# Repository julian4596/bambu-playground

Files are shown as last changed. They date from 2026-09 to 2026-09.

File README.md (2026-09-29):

# Ultralight Spacerless Gridfinity

Open `Ultralight_Spacerless_Gridfinity.scad` in OpenSCAD. Style 0 generates
open-bottom, rounded rings with chamfered seating faces and diamond-shaped
gaps where four cells meet. Drawer fitting and print-bed tiling remain available.

## Reference dimensions and reconstruction

The supplied reference screenshots measure a 2×2 plate at **84×84×4.25 mm**.
Their close-ups show sloped inner faces and a small lower transition, rather
than the previous flat opening and outward underside recess.

Paul Bone's [parameters.py](https://github.com/PaulBone/gfthings/blob/main/src/gfthings/parameters.py)
defines a 42 mm pitch and profile stages of 0.8, 1.8, and 2.15 mm.
[GFProfile.py](https://github.com/PaulBone/gfthings/blob/main/src/gfthings/GFProfile.py)
uses those stages for the chamfered profile. This is useful dimensional
reference, but its baseplate is not established as the model in the screenshots.
The local `gridfinity-rebuilt-openscad/src/core/gridfinity-baseplate.scad`
uses a related profile with a 0.7 mm lower chamfer and a 5 mm overall plate.
Neither source proves the exact 4.25 mm reference cross-section.

Style 0 therefore uses an explicit assumption: trim 0.5 mm from the bottom of
the 4.75 mm profile, retaining 0.3 mm of lower chamfer, 1.8 mm of straight wall,
and 2.15 mm of upper chamfer. The top opening remains 41.5 mm with 4 mm corner
radius; each cell's outer outline remains 42 mm with 4.25 mm corner radius.
The corresponding straight opening at the bottom is 36.6 mm, and at the middle
it is 37.2 mm. Straight outer rails are 0.25 mm at the top, 2.4 mm in the middle,
and 2.7 mm at the bottom; interior dividers have twice those widths.
These are derived candidate dimensions, not measurements of the reference.

Later underside close-ups show a recessed channel under each rail with a
sloping interior and narrow edge rims. Style 0 now subtracts a tapered rounded
annular channel under each cell, including around corners. The candidate defaults
are a 1.8 mm depth, 0.4 mm rims at the mouth, and a 0.3 mm wide channel roof.
The resulting mouth is approximately 1.9 mm wide along straight rails. Adjacent
cells retain a central rib between their channels. These relief dimensions are
visual estimates, not source-derived dimensions; `underside_relief_depth` and
`underside_relief_rim` expose the estimates for adjustment. `underside_relief`
can disable the channel. The earlier 2.7 mm bottom rail width describes the
envelope before this channel is subtracted.

Styles 1 and 2 retain the full 4.75 mm profile. This source is implemented in
OpenSCAD; the downloaded Python files under `reference/gfthings` are reference
material only and retain their original copyright and license notices.

## Comparison sample

`render_2x2.scad` selects a manual 2×2, style-0, untiled sample. Render it to
compare the candidate with the screenshots. Rendered artifacts are placed in
`output/reference-match/`. Dimensional and mesh checks do not establish printed
fit; the shortened underside profile remains a reconstruction assumption.

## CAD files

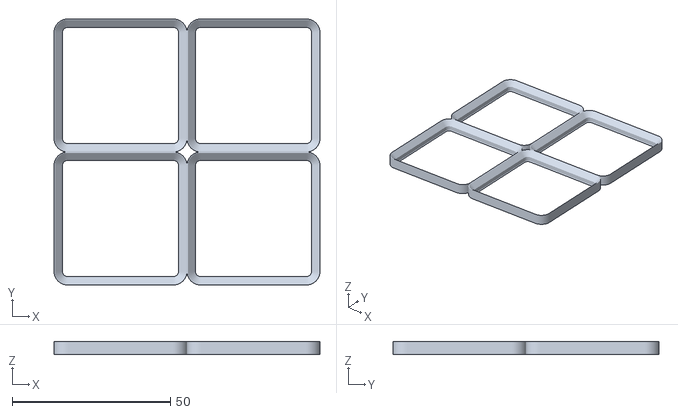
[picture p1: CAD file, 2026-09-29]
output/reference-match/lightest-2x2-relief.stl
84.0 x 84.0 x 4.25

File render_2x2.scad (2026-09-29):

// Parameters follow include so they override the included defaults.
include <Ultralight_Spacerless_Gridfinity.scad>
use_auto_fit = false;
manual_grid_x = 2;
manual_grid_y = 2;
style = 0;
clearance_per_side = 0;
tiling_mode = false;
enable_labels = false;

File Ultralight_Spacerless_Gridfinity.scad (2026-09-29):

// ============================================================================
// Ultralight Spacerless Gridfinity Baseplate
// ============================================================================
// A parametric, MakerWorld-compatible OpenSCAD script that generates
// ultra-lightweight Gridfinity baseplates that auto-fit your drawer
// dimensions with zero wasted space.
//
// Features:
//   - Spacerless auto-fit: input drawer dimensions, get a perfect fit
//   - Three styles: Ultralight (skeleton), Standard (thin floor), Solid
//   - Optional magnet and screw holes
//   - MakerWorld Customizer compatible
//
// Author: Julian (generated with AI assistance)
// License: CC BY-SA 4.0
// ============================================================================

// ---- Gridfinity Standard Constants ----
// These define the Gridfinity standard. Do not change unless you
// understand the Gridfinity specification.
GRID_PITCH     = 42;      // mm - standard grid unit size
TOLERANCE      = 0.25;    // mm - clearance per side (bin-to-baseplate)
WALL_MIN       = 1.2;     // mm - minimum wall thickness (3 × 0.4mm)
MAGNET_D       = 6.0;     // mm - magnet hole diameter
MAGNET_H       = 2.4;     // mm - magnet hole depth
SCREW_D        = 3.2;     // mm - M3 screw hole diameter

// Gridfinity baseplate pocket profile (cross-section, bottom to top):
//   Layer 1: 45° chamfer inward  — 0.8mm tall, narrows 0.8mm per side
//   Layer 2: Vertical wall       — 1.8mm tall, straight
//   Layer 3: 45° chamfer outward — 2.15mm tall, widens 2.15mm per side
CHAMFER_BOT_H = 0.8;
WALL_VERT_H   = 1.8;
CHAMFER_TOP_H = 2.15;
FULL_PROFILE_H = CHAMFER_BOT_H + WALL_VERT_H + CHAMFER_TOP_H; // 4.75mm
LIGHT_PROFILE_H = 4.25; // Overall height measured in the reference screenshots
// Shorten the open-bottom light plate without changing the upper seating profile.
LIGHT_BOTTOM_TRIM = FULL_PROFILE_H - LIGHT_PROFILE_H;

// Pocket dimensions (the void bins sit in)
// At the TOP of the pocket, the opening is the full cell minus tolerance
POCKET_TOP = GRID_PITCH - 2 * TOLERANCE;  // 41.5mm
// The mid-section (after top chamfer, before bottom chamfer)
POCKET_MID = POCKET_TOP - 2 * CHAMFER_TOP_H;  // 37.2mm
// At the BOTTOM, it narrows further
POCKET_BOT = POCKET_MID - 2 * CHAMFER_BOT_H;  // 35.6mm

// ============================================================================
// MakerWorld Customizer Parameters
// ============================================================================

/* [01 — Drawer Dimensions] */
// Inner width of your drawer in mm
drawer_width_mm = 400; // [50:1:1000]
// Inner depth of your drawer in mm
drawer_depth_mm = 500; // [50:1:1000]
// Clearance per side in mm (0.5 recommended)
clearance_per_side = 0.5; // [0:0.1:2]

/* [02 — Grid Override (Optional)] */
// Use auto-fit from drawer dimensions?
use_auto_fit = true;
// Manual grid units in X (only used if auto-fit is OFF)
manual_grid_x = 4; // [1:1:20]
// Manual grid units in Y (only used if auto-fit is OFF)
manual_grid_y = 4; // [1:1:20]

/* [03 — Baseplate Style] */
// 0=Super Light (4.25mm chamfered rings), 1=Standard (thin floor), 2=Solid (thick floor)
style = 0; // [0:Super Light, 1:Standard, 2:Solid]
// Recess a tapered channel into the underside of each light-style cell rail.
underside_relief = true;
// Estimated from reference views, not measured: channel height in mm.
underside_relief_depth = 1.8; // [0.2:0.1:2]
// Material retained at the inner and outer edges of the channel mouth.
underside_relief_rim = 0.4; // [0.3:0.05:0.8]

/* [04 — Extension Distribution] */
// How to distribute leftover space on each axis
// 0=Split evenly both sides, 1=Right/Back only, 2=Left/Front only
extension_mode = 0; // [0:Even Split, 1:Right-Back Only, 2:Left-Front Only]

/* [05 — Options] */
// Add 6mm x 2.4mm magnet holes at grid intersections
magnet_holes = false;
// Add M3 screw holes at grid intersections
screw_holes = false;

/* [06 — Print Bed Tiling] */
// Splitcut the generated plate (manual or auto-fit) into bed-sized tiles.
tiling_mode = true;
// Bed width in mm (tiling only).
bed_x_mm = 256.0; // [100:0.1:500]
// Bed depth in mm (tiling only).
bed_y_mm = 256.0; // [100:0.1:500]
// Reserved margin per bed edge in mm (tiling only).
bed_safe_margin_mm = 2.0; // [0:0.1:20]
// Gap between tiles in mm (scene only).
tile_gap_mm = 10.0; // [0:0.1:50]
// Add tile coordinate labels (tiling only).
enable_labels = true;
// Which part to render? 0=All (Exploded View), 1=Tile 1/1, etc.
part_to_render = 0; // [0:All (Exploded), 1:Tile 1/1, 2:Tile 2/1, 3:Tile 1/2, 4:Tile 2/2, 5:Tile 3/1, 6:Tile 3/2, 7:Tile 3/3, 8:Tile 4/1, 9:Tile 4/2, 10:Tile 4/3]

/* [Hidden] */
$fn = 40;
PROFILE_H = style == 0 ? LIGHT_PROFILE_H : FULL_PROFILE_H;

// ============================================================================
// Auto-Fit Calculation
// ============================================================================

_usable_w = drawer_width_mm - 2 * clearance_per_side;
_usable_d = drawer_depth_mm - 2 * clearance_per_side;

_auto_gx = max(1, floor(_usable_w / GRID_PITCH));
_auto_gy = max(1, floor(_usable_d / GRID_PITCH));

_left_x = _usable_w - _auto_gx * GRID_PITCH;
_left_y = _usable_d - _auto_gy * GRID_PITCH;

gx = use_auto_fit ? _auto_gx : manual_grid_x;
gy = use_auto_fit ? _auto_gy : manual_grid_y;

ext_tx = use_auto_fit ? max(0, _left_x) : 0;
ext_ty = use_auto_fit ? max(0, _left_y) : 0;

// Extension distribution
ext_L = (extension_mode == 0) ? floor(ext_tx / 2) :
        (extension_mode == 2) ? ext_tx : 0;
ext_R = (extension_mode == 0) ? ext_tx - floor(ext_tx / 2) :
        (extension_mode == 1) ? ext_tx : 0;
ext_F = (extension_mode == 0) ? floor(ext_ty / 2) :
        (extension_mode == 2) ? ext_ty : 0;
ext_B = (extension_mode == 0) ? ext_ty - floor(ext_ty / 2) :
        (extension_mode == 1) ? ext_ty : 0;

total_w = gx * GRID_PITCH + ext_L + ext_R;
total_d = gy * GRID_PITCH + ext_F + ext_B;

// Tiling calculations
// We reserve margin for the physical bed edge + ~15mm for puzzle joints & frame extensions
cells_per_tile_x = tiling_mode ? max(1, floor((bed_x_mm - 2 * bed_safe_margin_mm - 15) / GRID_PITCH)) : gx;
cells_per_tile_y = tiling_mode ? max(1, floor((bed_y_mm - 2 * bed_safe_margin_mm - 15) / GRID_PITCH)) : gy;

tiles_x = tiling_mode ? ceil(gx / cells_per_tile_x) : 1;
tiles_y = tiling_mode ? ceil(gy / cells_per_tile_y) : 1;

// Debug output
echo(str("=== Ultralight Spacerless Gridfinity ==="));
echo(str("Grid: ", gx, " x ", gy));
echo(str("Extensions — L:", ext_L, " R:", ext_R, " F:", ext_F, " B:", ext_B, " mm"));
echo(str("Total: ", total_w, " x ", total_d, " mm"));
echo(str("Style: ", style == 0 ? "Ultralight" : style == 1 ? "Standard" : "Solid"));
echo(str("Tiling: ", tiles_x, " x ", tiles_y, " tiles (", cells_per_tile_x, "x", cells_per_tile_y, " max cells per tile)"));

// ============================================================================
// Modules — Profile Geometry
// ============================================================================

module pocket() {
    if (style == 0) {
        // Reference shows sloped seating faces, not a flat through-opening.
        // Crop 0.5mm off the standard profile's bottom: remaining lower
        // chamfer 0.3mm, straight section 1.8mm, upper chamfer 2.15mm.
        // This crop is an explicit reconstruction assumption; see README.md.
        translate([0, 0, -LIGHT_BOTTOM_TRIM])
            standard_pocket();
    } else {
        standard_pocket();
    }
}

module standard_pocket() {
        // Standard Gridfinity 3-layer pocket profile.
        // Tiny overlapping slices avoid gaps between the hulls and wall.
        hull() {
            translate([0, 0, -0.01])
                rounded_centered_rect(POCKET_BOT, POCKET_BOT, 0.01, r=1.05);
            translate([0, 0, CHAMFER_BOT_H])
                rounded_centered_rect(POCKET_MID, POCKET_MID, 0.01, r=1.85);
        }
        
        translate([0, 0, CHAMFER_BOT_H - 0.01])
            rounded_centered_rect(POCKET_MID, POCKET_MID, WALL_VERT_H + 0.02, r=1.85);
        
        hull() {
            translate([0, 0, CHAMFER_BOT_H + WALL_VERT_H])
                rounded_centered_rect(POCKET_MID, POCKET_MID, 0.01, r=1.85);
            translate([0, 0, FULL_PROFILE_H])
                rounded_centered_rect(POCKET_TOP, POCKET_TOP, 0.01, r=4);
        }
        
        translate([0, 0, FULL_PROFILE_H])
            rounded_centered_rect(POCKET_TOP, POCKET_TOP, 1, r=4);
}
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

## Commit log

2026-08-19 Initial commit: add Ultralight Spacerless Gridfinity OpenSCAD file
    [Ultralight_Spacerless_Gridfinity.scad]
2026-08-19 feat: replace solid extension fills with lightweight ribs
    Instead of solid-filling the leftover space at the edges (which
    wasted significant material), the extension areas now use:
    - A thin perimeter wall (1.2mm) at the outer edge
    - Cross-brace ribs that extend each grid wall into the zone
    The amount of material saved is calculated automatically based
    on the auto-fit leftover dimensions.
    [Ultralight_Spacerless_Gridfinity.scad]
2026-08-19 feat: replace solid extension fills with lightweight ribs (#1)
    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
    [Ultralight_Spacerless_Gridfinity.scad]
2026-08-19 feat: automatic tiling and puzzle joints (#2)
    * feat: replace solid extension fills with lightweight ribs
    * feat: automatic tiling and puzzle joints
    * fix: properly center the exploded assembly and individual exported tiles
    * feat: update customizer variables to match UI standard
    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
    [Ultralight_Spacerless_Gridfinity.scad]
2026-08-19 feat: implement Super Light flat grid structure (#4)
    * feat: implement Super Light flat grid structure (no overhangs)
    * perf: reduce style 0 height to exactly 2.0mm to hit the 20g mass target for 4x4 grid
    * perf: implement 13g rounded pocket skeleton
    * fix: correct pocket height cut to properly carve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
    [Ultralight_Spacerless_Gridfinity.scad]
2026-08-20 feat: update style 0 to use fully 3D chamfered skeleton matching user design
    [Ultralight_Spacerless_Gridfinity.scad]
2026-08-20 feat: implement dual-level underside flange (stacking recess) for style 0
    [Ultralight_Spacerless_Gridfinity.scad]
2026-08-20 feat: update style 0 to use sweeping 3D chamfered stacking lip for V-groove look
    [Ultralight_Spacerless_Gridfinity.scad]
2026-08-20 feat: update style 0 outer radius to 4.25 for perfectly uniform walls and chamfered diamond holes
    [Ultralight_Spacerless_Gridfinity.scad]
2026-08-20 feat: style 0 uses flat-walled pocket with chamfered stacking lip for uniform walls and clean diamond holes
    [Ultralight_Spacerless_Gridfinity.scad]
2026-08-20 feat: match extension wall thickness to grid cell walls (0.25mm/side)
    [Ultralight_Spacerless_Gridfinity.scad]
2026-08-20 feat: render extensions as continuous bars for style 0 to fully replicate sparky design
    [Ultralight_Spacerless_Gridfinity.scad]
2026-09-29 feat: add tapered underside relief to 4.25mm lightest baseplate
    [Ultralight_Spacerless_Gridfinity.scad, lightest-2x2-relief.stl, render_2x2.scad]
